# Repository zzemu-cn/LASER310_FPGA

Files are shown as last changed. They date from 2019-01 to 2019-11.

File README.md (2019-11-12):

# LASER310 FPGA

Welcome to LASER310_FPGA project. This project is an attempt to recreate the once famous VZ300/Laser310 computer in 80's on Altera Cyclone based FPGA boards.

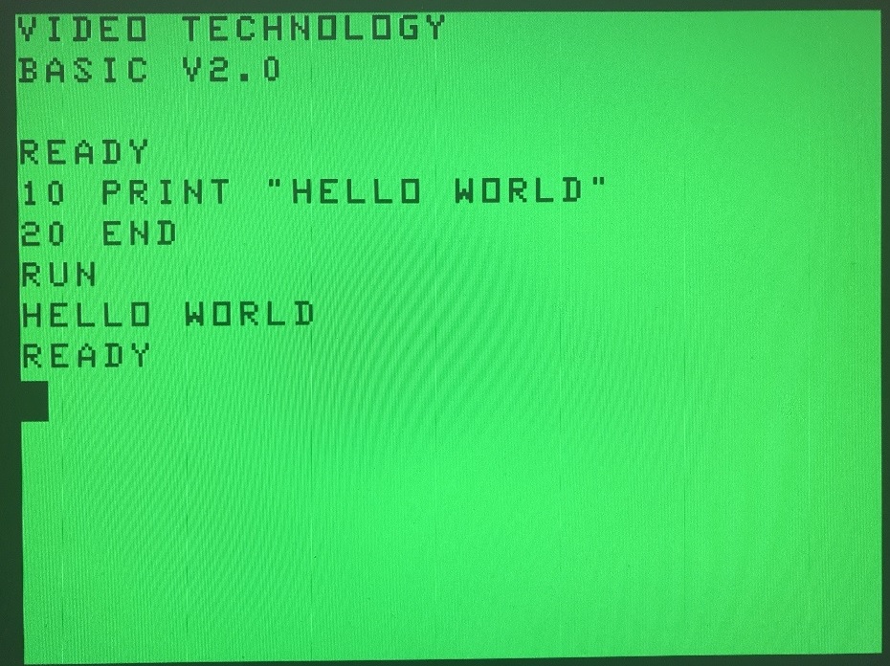
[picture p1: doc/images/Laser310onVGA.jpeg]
Laser310 on VGA


***Software requirment:***   
Quartus 13.0 web edition for projects except DE0_CV. For DE0_CV, you need 18.0 or newer.   

***Features implemented:***
1. MC6847 /w VGA output
2. Super high resolution mode (256*192)
3. Cassette input/output emu
4. Laser310 internal ROM/DOS ROM on flash
5. Enable external ROM with onboard switches at runtime.
6. VZ200 support
7. 256K RAM module
8. Buzzer output
9. PS/2 keyboard support (Ctrl+F12 to reset).
10. 12.5MHz overclock on SW0

***Planned***

1. Z80 bus on GPIO mapping.
2. Floppy emu support

***Screenshots***  
IORQ output n,5 captured on GPIO1  
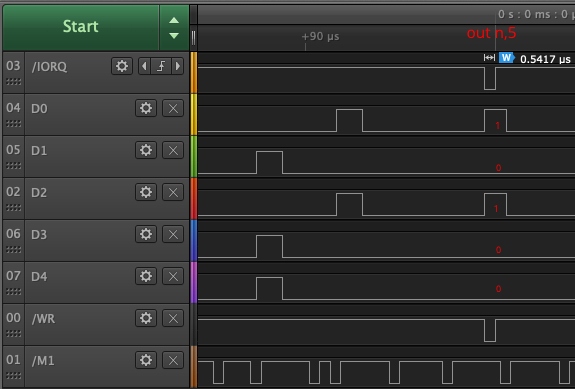
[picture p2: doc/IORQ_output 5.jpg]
IORQ on output
  

***Supported boards***

- Terasic DE0
- Terasic DE0_CV
- Terasic DE1
- Terasic DE2
- Terasic DE2-70
- Terasic DE2-115

***Folder structures***

doc_LASER310:

Laser310 Ext Basic P1.5c and user manual.

Laser310 System B and user manual.

Laser310 Monitor and user manual

Cassette output encoding details.

Laser310 keyboard encoding schema

Laser310 oscilloscope screenshot of cassette output 

rom:

VZ300/Laser310 roms

Software:

development tools for this project. 

vz:

Some come games for testing.

SYSTEM-B.vz is a binary file loading/saving tool for cassette/disk on Laser 310.

BASIC_P1.5C.vz is an extended Basic for Laser 310 developed by XinMin Peng in 80's.

MONITORR.vz is a Laser 310 system monitor.

More details on these VZ300/Laser310 softwares to follow.

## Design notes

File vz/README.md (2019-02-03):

System B : Utility for loading and saving binary files. See [instructions](./SYSTEM-B.md) here.  
Monitor :  Z80 monitor runs on Laser310  
Basic P1.5C : Ext. Basic P 1.5C

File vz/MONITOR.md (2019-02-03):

Laser 310 Z80 Monitor instructions:

Entrying Monitor from Laser 310 Basic environment:
MON

Commands:
  * A - 
  * D - 
  * I - Cassette input
  * O - Cassette output
  * W - Write
  * F - Display HEX values
  * L - 
  * M - Memory block move
  * B - Breakpoint
  * E - Execute
  * R - Register display
  * X - 
  * D - Print

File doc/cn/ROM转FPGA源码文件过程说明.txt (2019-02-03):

环境：Windows 10 64位版本。
软件：php

一、php 安装设置
    转换程序是用 php 编写的，需要安装 php 解释程序。
    通过php官方网站下载。
    http://php.net/
    https://windows.php.net/download/

   下载最新版本
   https://windows.php.net/downloads/releases/php-7.3.1-nts-Win32-VC15-x64.zip
   解压缩到 C:\php 目录，并加入到系统执行路径PATH中。

   运行php需要安装对应的MS的VC运行库。
   https://aka.ms/vs/15/release/VC_redist.x64.exe
   https://aka.ms/vs/15/release/VC_redist.x86.exe

   在windows命令行执行 php -v 看是否能够执行。

二、对字库文件进行调整
    这里有个特例，就是需要对字库文件进行调整。
    LASER310的字符点阵（8 x 12点阵256个字符）行数不是2的倍数，不转换，编写视频模块很困难。

三、把 rom 转换为对应的 mif 文件
    fpga 中的 rom 加载有两种方式：一是把 rom 直接写入 flash 芯片。另一种就是用fpga芯片自带块ram来仿真rom。
    为了便于不同开发板之间的移植，该设计方案采用的是块内存来实现rom。
    编译（综合）项目前，需要把 rom 的二进制文件转换为源文件。

    例如，在项目目录为D:\LASER310_FPGA时，命令如下：
    D:
    cd D:\LASER310_FPGA_prj\LASER310_FPGA\rtl
    php gen_mif.php ..\rom\VZ200_4K.FNT charrom_4k.mif
    php gen_mif.php ..\rom\vtechv20.u12 sysrom.mif
    php gen_mif.php ..\rom\vzdos.rom dosrom.mif
    php gen_mif.php ..\rom\boot_rom.bin boot_rom_6000.mif

    这四条命令分别把字库字模文件、系统rom文件、磁盘rom文件、自动化加载程序 转换为FPGA的rtl源代码。

四、生成模拟磁带模块的预装载数据
    模拟磁带模块可以设置一个默认的装载磁带数据。可以通过命令把 vz 文件转换为FPGA的rtl源代码。
    例如，在项目目录为D:\LASER310_FPGA时，命令如下：
    D:
    cd D:\LASER310_FPGA\rtl
    php vz2mif.php ..\vz\PUCKMAN.AC3A.vz cass_ram.mif
    php vz2mif.php ..\vz\SYSTEM-B.vz cass_ram_4k.mif
    php vz2mif.php ..\vz\MONITORR.vz cass_ram_4k.mif

    根据选定的模拟磁带缓冲区大小，生成对应的文件。
    cass_ram.mif
    cass_ram_4k.mif
    cass_ram_8k.mif
    cass_ram_16k.mif

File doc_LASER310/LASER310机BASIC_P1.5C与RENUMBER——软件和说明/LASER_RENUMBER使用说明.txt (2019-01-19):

摘录自《Laser310微电脑软硬件系统剖析》彭辛岷

LASER RENUMBER
功能：
（1）重编BASIC程序行号，并相应修改下列语句中的目标行号参数：GOTO，IF…THEN…ELSE，GOSUB，RUN，LIST，LLIST，ON…GOTO，ON…GOSUB，ONERR，RESUME，DEL，POP，以及用直接行号作参数的RST语句；
（2）优先使用显示文本区存放数据，处理300个以下的句内行号参数可不占用户程序区；
（3）能将程序中有错误的行号参数首字符变成字母（以A~J代替0~9），提示用户修改；
（4）处理过程中发生内存不够使用时可报告当前处理到的行号，以便删节后再重编；
（5）两个以上程序拼接后（行号不成升序）重编，可保证各自目标行号不致错乱；
（6）产生过大行号（≥60000）时能自动加以调整；
（7）速度快，安全性好。

软件制作方法：将机器码按址送入内存后，将其首、末地址置入用户程序首、末址指针单元，存盘或记带；以后用BLOAD（磁盘）和CLOAD（磁带）装入内存。用CLOAD装入后应执行NEW以修正程序区指针（如先已有BASIC程序，可再用PRINT&PST恢复之）。

调用方法：
（l）本程序须在Pl.5D系统支持下方能处理扩展功能语句；P1.5D是将P1.5C文本中7D2FH~7D39H的内容改为“F5 E5 21 12 75 CD A4 06 C3 4A 1E”，将7B9FH的内容改为44H而成。调用的命令为：RENUN首行行号，行号增量；语法规则不变。
（2）在V2.0支持下，可用USR函数调用，入口地址为74D6H，执行POKE 30862,214:POKE 30863,116后，调用格式为：A=USR(0)'首行行号,行号增量（注意号'不能省略）；参数用法同P1.5。

注意：
（1）本程序因利用显示RAM，运行中荧光屏出现点线干扰及图案字符，均属正常现象；
（2）使用MODE(1)会清除本程序，用USR调用前请证实程序的存在；
（3）重编后程序长度改变，请留心与程序中USR、POKE等有关的地址是否变化；
（4）对REM、PRINT等语句不作处理，

请注意原来有关行号的注释和屏幕提示是否仍然正确，以及使用&ERL（出错行号函数）的语句内容。

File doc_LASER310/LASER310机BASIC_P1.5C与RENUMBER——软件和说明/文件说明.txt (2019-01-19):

目录下的两个程序来自《Laser310微电脑软硬件系统剖析》彭辛岷

根据书中的代码建立了两个文件
LASER_BASIC_P1.5C.txt
LASER_RENUMBER.txt

然后通过命令 php hex_txt2bin.php 生成
BASIC_P1.5C.vz
BASIC_P1.5C.7B04.bin

RENUMBER.vz
RENUMBER.74D3.bin

bin 只含有数据，可以用来反汇编学习。

由于对原书中的程序字符识别可能出现差错，不能保证生成的程序与原始代码一致。

hex_txt2bin.php 是转换脚本源程序。

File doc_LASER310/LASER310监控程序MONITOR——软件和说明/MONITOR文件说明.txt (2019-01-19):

LASER310监控程序MONITOR文件说明

MONITORR 原版的MONITOR程序
MONITOR 解密版的MONITOR监控程序

MONITOR是一个Laser-310监控程序，这个程序类似于Apple II 的Call-151，可以读写内存，汇编，反汇编等。但是因为太大16K内存的310上基本上只能看ROM的内容，加装了16K/64K卡的机器，用这个程序比较实用。

命令：
MON 由BASIC进入MONITOR
E 退出MONITOR返回BASIC

--------------------------------

Monitor发行版是加密的，一加载就自动运行。并且破坏现场。也就是说从monitor里也没法录它自己。
文件MONITOR是由上海董启文解密录制的。
原版MONITOR可以用“B文件系统”直接解密。
MONITOR的使用说明是Bill的笔友张浩写的。

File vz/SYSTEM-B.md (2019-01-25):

Laser310 System B readme  

System B is a utility published on Aug 16 of 1987 issue of "Software" journal. Authors are Luo, Shouzhang and Luo, Ya.
When loading a binary file from cassette on Laser 310, the ROM binary program loader will automatically make a call to the entry point and start running it.
With this utility you can load a binary file from cassette and floppy, make a copy of this file to casette.  

The System B itself is only 190 bytes, designed to be loaded to the high end of display RAM.
Commands:  
R ["filename"] - Load binary file from cassette  
L "filename" - Load binary file from floppy  
W ["filename"] - Write file to cassette as binary file  
V ["filename"] - Verify binary file on cassette  
E - Exit from system  

Notes:  
* System B is compatible with Laser 310 Monitor and DOS Basic 1.2 or any file lives from 7AE9 to B7FF and 7200 to 76FF.
* L command is NOP on diskless system.
* W command will create an identical copy of loadded B file, runs well without System B.
* R/L command, it stores the start address and end address in 77BB and 77BE. They remain unchanged after you exit from System B.
* System B is loadded in high-end of VRAM, MODE(1) command will clean this area.

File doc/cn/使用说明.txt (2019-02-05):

开关0 加速模式 TURBO_SPEED
开关1 加载 DOS ROM
开关2 扩展绘图模式支持 SHRG

开关4...6 地址0000H 16K系统 ROM 切换
开关7...9 地址4000H 8K ROM 切换

键盘功能：上下左右，右Shift，Esc模拟Ctrl-Break, Backspace左
Ctrl+F12 系统复位 reset
button0 系统复位 reset

Ctrl F1 ... F8  Auto Start ROM 自动化加载程序 固化程序 4000 D000 E000 F000
L-Ctrl F1 ... F8 自动化加载 vz 文件，启动代码未完成

左line in录音输入
左line out录音输出

右line out喇叭输出

vz 可以通过 WAV2VZ.exe 转换为 wav 文件。

================================

虚拟磁带
敲入命令 CRUN
（下步改进，自动输入CRUN命令）
F9  播放 RAM 缓冲区的磁带数据
F10 停止播放

可以通过software目录下的emu_cass_key_gui.exe上传vz磁带文件

================================

虚拟键盘
通过串口通信软件，如 putty
设置 57600 8
插入LF

特殊命令
按键      操作
_         播放虚拟磁带
Backspace 左移动
Ctrl+C    Ctrl+Break
Return    Return

可以接受的字符输入
数字 大写 符号 图形字符（对应的小写）

================================
编译项目
目前支持的开发板
友晶的 ALTERA DE0
友晶的 ALTERA DE1
友晶的 ALTERA DE2
友晶的 ALTERA DE2-70
友晶的 ALTERA DE2-115

编译前，需要修改源文件 LASER310_FPGA\rtl\LASER310_TOP.v

//`define	DE0
`define	DE1
//`define	DE2
//`define	DE2_70
//`define	DE2_115

打开对应的选项。

进入目录 LASER310_FPGA\rtl
通过 mif 文件生成ROM。
php gen_mif.php ..\rom\VZ200.FNT charrom.mif
php gen_mif.php ..\rom\VZ200_4K.FNT charrom_4k.mif
php gen_mif.php ..\rom\vtechv20.u12 sysrom.mif
php gen_mif.php ..\rom\vzdos.rom dosrom.mif
php gen_mif.php ..\rom\boot_rom.bin boot_rom_6000.mif

生成默认的模拟磁带数据:
php vz2mif.php ..\vz\BASIC_P1.5C.vz cass_ram_4k.mif
php vz2mif.php ..\vz\BASIC_P1.5C.vz cass_ram.mif
php vz2mif.php ..\vz\MONITORR.vz cass_ram.mif
php vz2mif.php ..\vz\SYSTEM-B..vz cass_ram.mif
php vz2mif.php ..\vz\PUCKMAN.vz cass_ram.mif

也可以通过命令
vz2mif.exe 02.vz 02.mif

================================
烧录ROM文件
随着系统功能扩充，部分开发板的片上内存不足，需要使用FPGA外接 flash 来存储 ROM数据。
目前 DE1 和 DE2 开发板需要烧写 FLASH。

首先要生成写入 FLASH 的二进制数据文件。
执行
 CD flash_build
 php gen_rom.php 可以生成 flash_rom.bin 这个文件。

对于友晶的DEx系列开发板，厂商提供了烧写 FLASH 的工具 DEx_control_panel，可以在最新的随机光盘文件中找到。
对于DE1开发板，可以参考“DE1烧写flash的方法.txt”。
通过FLASH烧写工具，把文件 flash_rom.bin 写入开发板。记得先擦除后烧写。

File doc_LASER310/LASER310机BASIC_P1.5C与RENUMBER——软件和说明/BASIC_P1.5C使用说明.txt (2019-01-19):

摘录自《Laser310微电脑软硬件系统剖析》彭辛岷

P1.5的扩展功能

    本系统在V2.0的基础上，发据出Level II的全部功能，模拟了APPLESOFT和PC-1500 BASIC的部分功能，还具有一些上述系统都不具备的独特功能。扩展的语句命令和函数共计四十三种。现将保留词、用法和功能简介如下。

    系统功能
    （1）BYE
	退出
    退出P1.5，重新启动V2.0。

    BASIC程序管理功能
    （1）AUTO 首行行号，行号增量
	自动产生行号
    按给定参数自动产生行号，接受输入的程序行。回车后按增量产生下行行号……直至行号>65529或按了BREAK为止。如某一参数缺省则自动设为0。程序区已有与所产生的行号相同的程序行时，显示该行，光标在行末。

    （2）RENUN 首行行号，行号增量
    重编行号
    可按规定系列将程序行号全部重编，某一参数缺省时自动设定为10。因系统规模所限，本功能仅为简易型，不处理语句中的目标行号，需用户自行修改。如需全部用程序处理，请采用笔者开发的“LASER RENUMBER”程序。

	（3）DEL 起始行号——结束行号
	成片删除
    删除指定范围的全部程序行；如起始行号缺省，则删除指定行号及它前面的所有行。

	（4）PLOAD “文件名”
	拼接读带
    在保存内存中现有文件的同时，从磁带上装入一个BASIC文件，以便二者拼接。
    （5）MERGE
	程序拼接
    用PLOAD命令装入供拼接的程序后，此命令可将它同内存原有程序拼接为一个程序。后调入程序排列在前，原有程序接在其后；并不按行号大小顺序。如拼接后行号顺序颠倒，仍可按排列顺序执行，但GOTO等语句可能出错，所以一般应重编行号。
    （6）MERGE 0
	撤销拼接
    当错调拼接文件，装载出错或意图改变时，此命令可清除装入的内容，恢复原有程序
	（7）PRINT&PST
	恢复被清除的程序
    可恢复被NEW命令清除的BASIC程序。如NEW后又键入了新的程序行，只要尚未达到原来程序的长度，亦可部分恢复显示（首行可能不正确），但程序首址已变为当前地址。如NEW后使用过Pl.5扩展命令，或在直接命令中使用过变量，也只能恢复未被新的变量区覆盖的部分。以上两种情况都可用LOMEM 0命令使残余程序段复位到程序区起始端。

    机器语言程序管理功能
    （1）LOMEW低端地址
	低端内存保护

——84——

    设定BASIC程序区起始地址，从7B04H（31492）到设定地址的前一单元，不受系统的控制，为用户所有。在已经输入BASIC程序以后，仍可用此命令开辟保留区；已开辟保留区还可重新改变其地址。BASIC程序将自动在内存中移动，不会遭到破坏。地址参数取十进制正值（31492~65535），保留区内用户可用来存贮数据的最低地址为31492，前面是预置的BASIC启动程序。

	（2）LOMEM 0
	撤销保留区
    清除保留区数据，BASIC首址前移至7AE9H，程序不受影响。

	（3）CALL 入口地址
	调用机器语言子程序
    从指定地址开始执行机器程序，遇到返回指令时返回BASIC程序的断点继续运行。地址参数取十进制正值（0~65535）。

	（4）SAVEB “文件名”
	二进制文件写入磁带
    将低端用户保留区7B04H以后的全部内容，以二进制格式存贮在磁带上。记带期间禁按BREAK。

	（5）SAVEA “文件名”
	二进制/BASIC复合文件写入磁带
	将BASIC程序连同保留区内全部信息以BASlC文本文件的格式记入磁带。以后装入内存可自动调整指针，并启动BASIC程序。

	显示功能
    （1）SPEED 延时值
	显示、打印速度控制
    设定显示每一行之间的延时值。取0为正常速度，取1~256时间间隔次第加长，SPEED 256时显示行间约间隔一分钟。延时对显示、打印数据及程序清单均有效。中途按“.”键，恢复正常速度。

	（2）&P0S(0)
	取光标的行位置
    其值为光标在当前的行中的位置（0~31）

	数据处理功能
	（1）DEFDBL 字母或字母范围
	定义双精度变量
    把以指定字母开头的变量都定义为双精度变量，使能保持16位有效数字；带类型标志$、%和！者除外。赋给双精度变量的数值应该是双精度的，否则六位以后的数字无意义。精度常数用#号标注。不同精度的变量或数值间进行运算时结果为较高精度类型。字母可分别指定，用逗号分隔，也可按英文字母表的顺序，指定范围，如DEFDBL N, M, D-G。

	（2）DEFINT 字母或字母范围
	定义整型变量
    将以指定字母开头的变量都定义为整型（带$、！标志者除外），存放整数（32767≥N≥-32768）。用法同上。

    （3）DERSTR 字母或字母范围
	定义字符串变量
    将以指定字母开头的变量均定义为字符串型（带%、！标志者除外）。用法同上。

	（4）DEFSNG 字母或字母范围
	定义单精度变量
    将以指定字母开头的变量均定义为单精度型（带%、$标志者除外）。由于系统初始化时已将所有变量均定义为单精度型，它一般只在重新定义时使用。用法同上。变量重新定义后即失去原有的值。

	（5）&CDBL(表达式)取双精度值

——85——

    函数为自变量的双精度值。

    （6）&CSNG(表达式)
	取单精度值
    函数为自变量的单精度值。如自变量是双精度时，多余位数四舍五入。

    （7）&CINT(表达式)
	取整型值
    函数为自变量的整型值（不大于自变量的最大整数）。自变量的范围是：32767≤N≥-32768。

	（8）&FIX(表达式)
	数值截尾
    取自变量的整数部分。当自变量为负数时，函数值将大于自变量。如：&FIX(-3.14)=-3，而INT(-3.14)=-4。

	（9）&STRING$(长度,字符)
	同一字符的字符串
	函数值为由指定的同一字符组成的、指定长度的字符串。参数可为表达式。长度受字符串区容量的限制；要先用CLEAR开辟足够的空间。字符串自变量多于一个字符时，只取首字符。

	（10）RANDOM
	打开随机数发生器
    由于产生RND函数的种子值是一定的，并由同一子程序计算而得，所以只是伪随机数。
在调用RND之前使用本语句，可用当时CPU刷新寄存器的值改变种子值，增加RND函数的随机性。

    监测功能
    （1）TRON
	打开跟踪功能
    BASIC程序运行时将显示所执行的每一行号。

	（2）TROFF
	关闭跟踪功能

	（3）&LAD(表达式)
	取行地址
    自变量为一行号值。函数值为此行在内存的首址。

	（4）&VARPTR(变量名)
	取变量地址
    函数值为指定变量在变量区的首址。

	（5）&MEM
	取空闲内存字节数
    函数值为当前BASIC程序尚可使用的内存空间剩余字节总数。

	（6）&FRE(字符串变量名)
	取空闲字符串区字节数
	函数值为当前字符串区尚可使用的字节总数。自变量可用任一字等串变量名。

	BASIC程序控制功能
    （1）RST 表达式
	重置读数据指针
    参数为一行号值；将读数据指针指向该行，READ语句将从此行开始从BATA语句中读取数据。

    （2）ON 表达式 GOTO 行号1，行号2……
	控制转移根据表达式的值N，转移到第N个行号的行去继续运行。如N大于行号个数，或N<1，则不转移，顺序执行下一语句。

	（3）ON 表达式 GOSUB 行号1，行号2，……
	控制调用子程序
	根据表达式值N，决定调用第N个行号为入口的BASIC子程序。规则同上。

	（4）POP 行号
	清栈转移

——86——

    在用GOSUB转入子程序后，如不需要返回原来的断点，此语句可在执行RETURN清除堆栈功能后，转向指定行号继续运行。

	错误处理功能
    （1）ONERR GOTO 行号
	进入出错转移状态
    此后程序出错时，不再中断运行和显示错误信息，而是转到本语句指定的行号（一般是一个处理错误的子程序入口）去继续运行。

	（2）ONERR GOTO 0
	终止出错转移状态
    取消上一个ONERR语句的作用。如在已经出错并转移后执行此语句，就停止运行，显示原来的错误信息。

	（3）&ERR 取错误代码
    函数值为当前的错误代码，可用以辨别错误的性质。

	（4）&ERL 取出错行号
    函数值为当时产生错误的行号。直接命令出错时其值为65535。

	（5）RESUM 0
	返回到出错的语句
    由于ONERR语句的作用捕获到错误并转入错误处理子程序后，须用RESUE语句结束返回，否则仍处于捕获错误的状态，系统将拒绝处理下一次的错误。本语句是返回出错语句重新执行，之前应采取措施使得错误不再发生，否则陷入无限循环。

	（6）RESTME NEXT
	返回出错语句的下一个语句
	可用来跳过产生错误的语句。

	（7）RESEME 行号
	返回并转移
    从出错状态中返国并转移到指定行号继续运行。

	（8）ERROR 错误编号
	模拟错误
    执行此语句的作用，等效于发生该编号的“错误”。可用于调式错误处理子程序。错误编号=错误代码/2+1。错误编号范围为0~23，如参数值超出，本身就是一种错误（错误编号出界，&ERR=38）。

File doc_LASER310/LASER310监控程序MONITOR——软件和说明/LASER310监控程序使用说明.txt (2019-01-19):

LASER 310监控程序使用说明
张浩

命令：MON 由BASIC进入MONITOR

1、汇编命令A
功能：汇编Z-80指令，并将机器指令码存入内存。
格式：As 键入该命今后，屏幕将显示地址s和汇编提示“ASM...”，等待用户输入Z80指令机器码。用户完成输入后，按下回车，助记符便被会变成指令机器码，并存入从地址s开始的内存单元。

2，反汇编列表命令D
格式：Ds,e
从地址s开始，到地址e结束，列表显示Z80助记符。如e省略，Ds 从地址s开始，列表显示10行助记符。

3、磁带输入命令I
格式：I
从磁带当前位置开始，将遇到的第一个磁带文件装入内存，并显示起止地址。
格式：I:f
把“f”为文件名的文件装入内存。

4、磁带输出命令O
格式：Os,e,f
将起始地址为s，结束地址为e的二进制文件，以f为文件名存入磁带。

5、写入命令W（十六进制）
格式：Ws 键入该命令后，屏幕将显示地址s和s中的内容。当用户键入数据，并按下回车后，新的数据被写入s单元中。如果用户名键入引号后，直接键入字符，该字符的ASCII便写入s中。按下“.”，退出写命令。

6、显示命令F（十六进制）
格式： Fs,e
显示从地址s到e间的数据。如e省略，Fs显示从s开始的8x10个字节数据。

7、显示ASCII码命令L
功能：显示内存中的ASCII码和ASCII码所代表的字符。
格式：Ls,e
同Fs,e

8、数据块移动M
格式：Ms,e,d
将地址s到e中一段数据，移动到以d开始的内存空间，源地址内容不变。

9、设置断点B
格式：Bs
在程序地址s中设置断点，当程序运行到断点时，自动显示所有寄存器的当前内容，并返回MONITOR。

10、消除B命令所设置的断点
格式：C

11、程序运行命令E
格式：Es
从地址s开始运行Z-80程序
格式：E
退出MONITOR，返回BASIC

12、寄存器操作命令R
格式：R
显示所有寄存器在程序中断后的内容
格式：Rr,d
将寄存器r中的内容改为d

13、十进制与十六进制互换X
功能：十进制范围为 0——32767，-32768——-1，十六进制0H——FFFFH
格式：XDd
将十进制数d转为十六进制数
格式：XHh
将十六进制数h转为十进制数

14、打印命令D
格式：Dm
用打印的形式完成监控命令，m为D、F、L等。

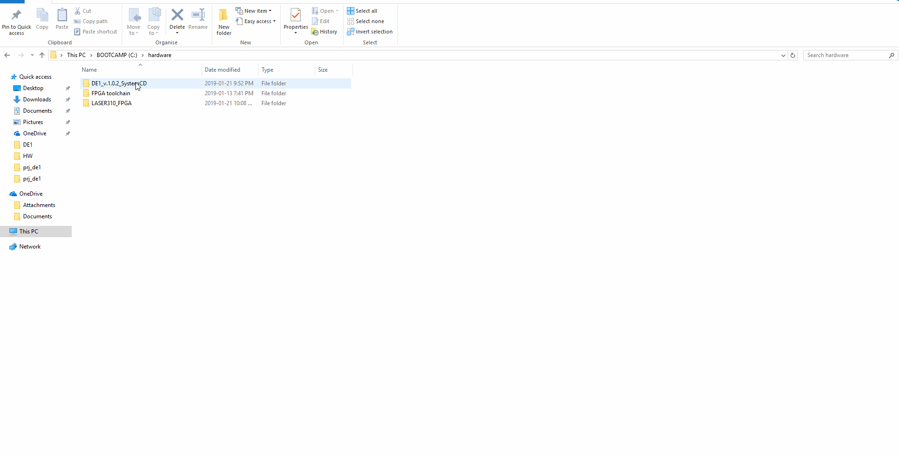
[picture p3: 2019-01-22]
doc/screen_recordings/program flash with ROM bin file.gif

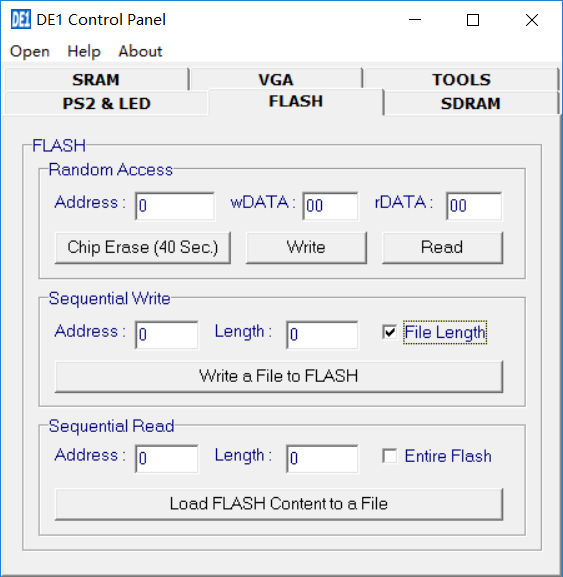
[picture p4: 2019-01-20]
doc/cn/pic4.png

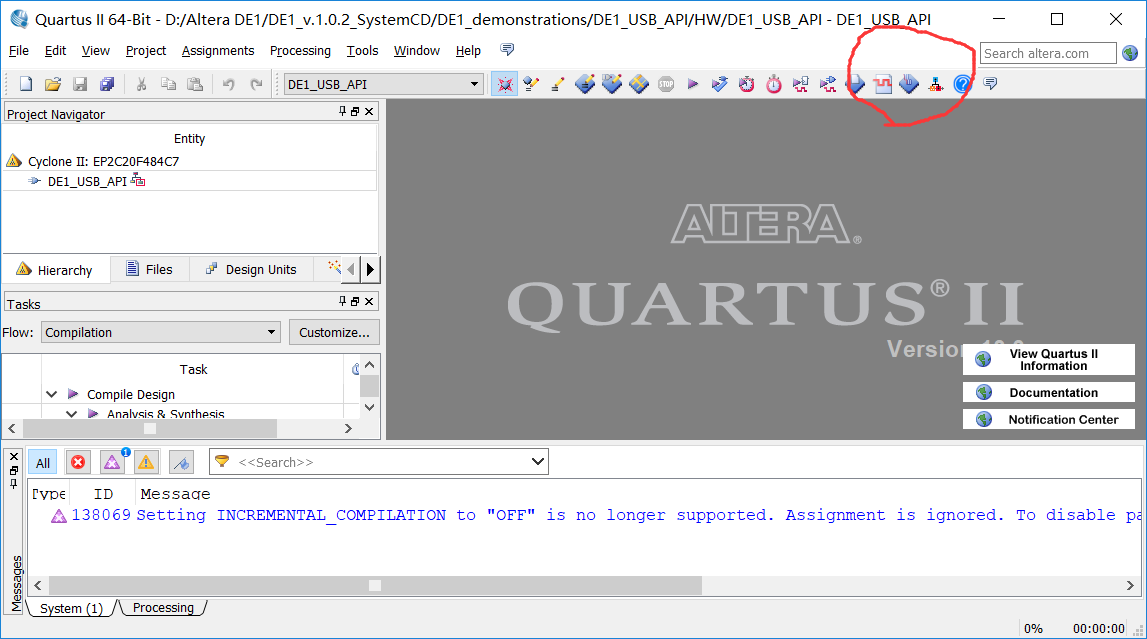
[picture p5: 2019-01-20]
doc/cn/pic1.png

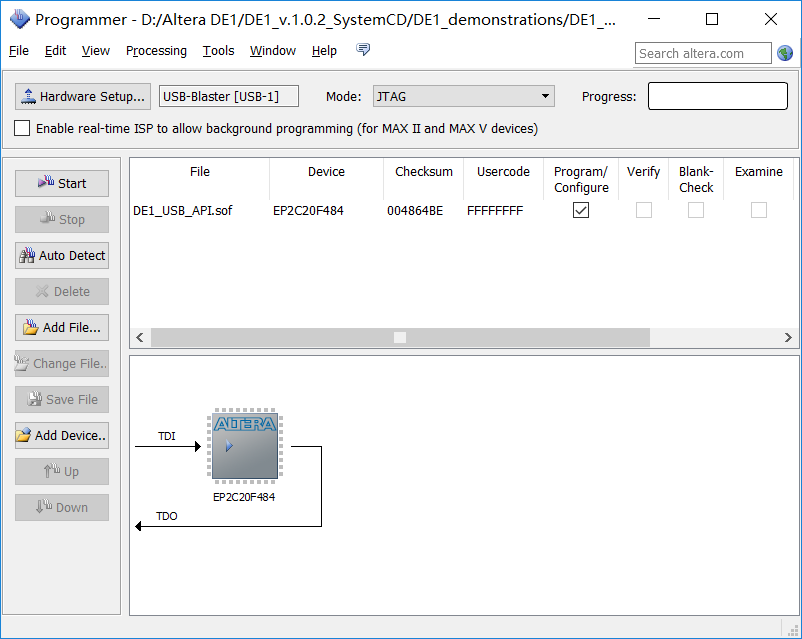
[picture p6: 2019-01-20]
doc/cn/pic2.png

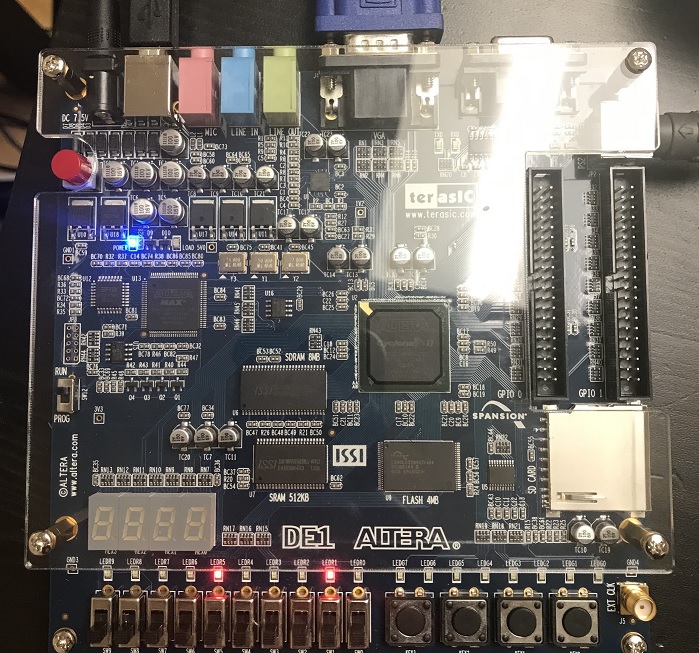
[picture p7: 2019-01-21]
doc/images/DE1.jpeg

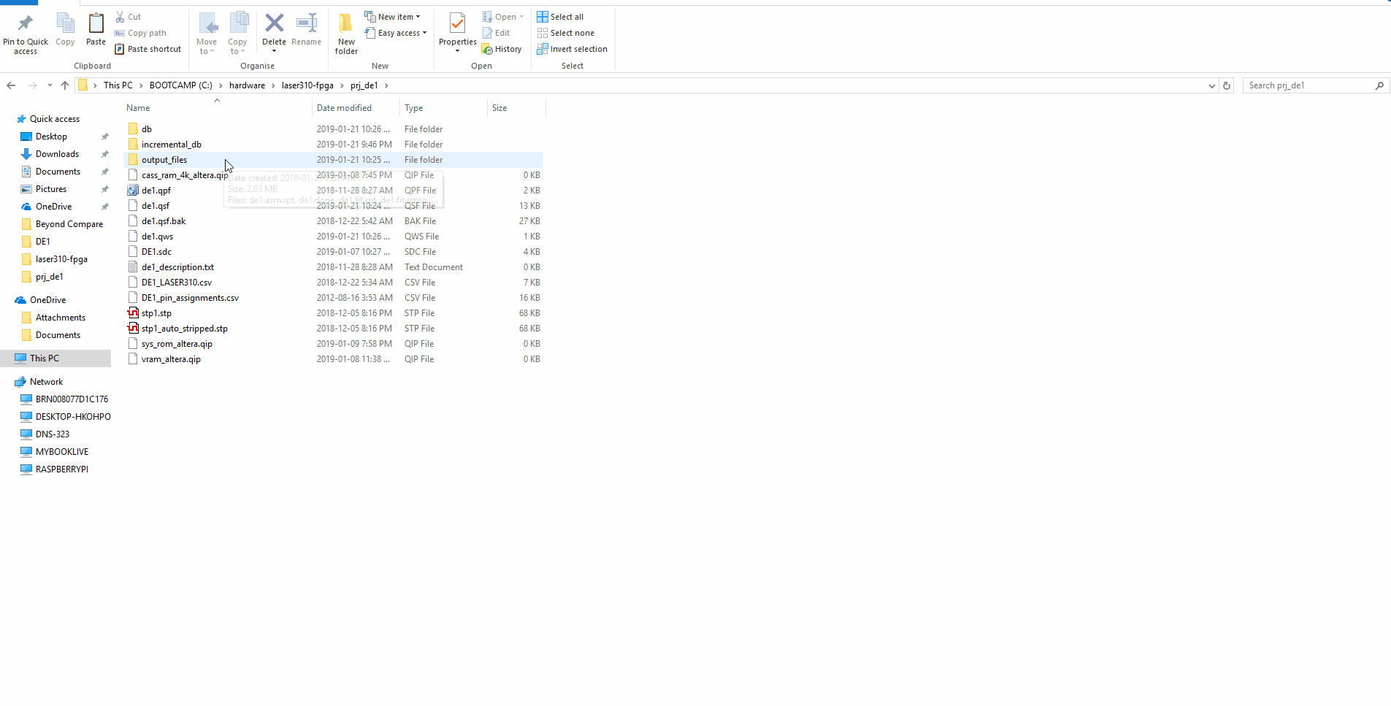
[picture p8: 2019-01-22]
doc/screen_recordings/laser310_fpga_w_built_in_rom.gif

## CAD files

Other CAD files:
prj_de0cv/stp1_auto_stripped.stp
prj_de1/output_files/stp1.stp
prj_de1/stp1.stp
prj_de2_70/output_files/stp1_auto_stripped.stp
prj_de0cv/stp1.stp
prj_de1/output_files/stp1_auto_stripped.stp
prj_de1/stp1_auto_stripped.stp
prj_de2_70/output_files/stp1.stp

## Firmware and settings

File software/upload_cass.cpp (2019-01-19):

// g++ -std=c++17 -o upload_cass upload_cass.cpp vz2cass.cpp UART.cpp -mconsole -DMINGW_HAS_SECURE_API -D_FILE_OFFSET_BITS=64 -IC:/MinGW/include
#include <cstdint>

#include <cstdio>
#include <cstdlib>
#include <cstring>

#define DBG
#include "upload_tool.cpp"

int main (int argc, char *argv []) {

    //char *port = malloc (sizeof (char) * 12); // Just for "straight to test purposes", in production, use the port detection functions instead
    //strcpy(port, "\\\\.\\COM3");

//------------------------------------ Stand-alone function to do their straight work the most synchronous way ------------------------------------

//    AVAILABLE_PORTS *ports;                         // Initializing the struct values
//    ports = malloc(sizeof(AVAILABLE_PORTS));
//    updateAvailablePortsInfo(ports);                // Setup/load time, the function will update the living struct

	int	uart_com_no = 0;

	uint8_t		vz_buf[1024*64];
	uint8_t		buf[1024*64];
	uint32_t	mif_len;
	size_t		vz_len;

    if(argc<2) {
		fprintf(stderr, "usage: upload_cass COMx name.vz\n");
		return 1;
	}

	uart_com_no = getCOMx(argv[1]);
	if(uart_com_no==0) { printf("COMx err %d", uart_com_no); return 1; }

	int err = vz_upload (argv[2], uart_com_no);

	if(!err)
		printf("uploaded completed");

    return err?1:0;
}

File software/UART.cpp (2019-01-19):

/****************************
 *	Module:	UART			*
 *	Author:	Josh Chen		*
 *	Date:	2014/05/15		*
 ****************************/


#include <stdio.h>
#include <windows.h>
#include "UART.h"


//********** Global Variable **********//

#define RX_TIMEOUT      10
#define TX_TIMEOUT      500
#define BUF_SIZE        512
#define MAX_COM_NUM     256

char            UARTErrBuf[BUF_SIZE] = {0};
int             CurrComPort = 0;
HANDLE          UARTHandle[MAX_COM_NUM] = {NULL};
unsigned char   UARTRxBuf[BUF_SIZE] = {0};
unsigned int    UARTRxBufCnt = 0;


//********** Private Function **********//

static void __UartSetLastErr(const char *err, ...)
{
    char szBuf[BUF_SIZE];
    va_list vl;

    memset(UARTErrBuf, 0, sizeof(UARTErrBuf));
    if (NULL != err)
    {
        memset(szBuf, 0, sizeof(szBuf));
        va_start(vl, err);
        vsprintf(szBuf, err, vl);
        va_end(vl);
        sprintf(UARTErrBuf, "*** UART - %s ***\r\n", szBuf);
    }
}

static void __UartSleep(unsigned long ms)
{
    DWORD   beginTick;
    MSG     msg;

    beginTick = ::GetTickCount();
    do
    {
        if (::PeekMessage(&msg, NULL, 0, 0, PM_REMOVE))
        {
            ::TranslateMessage(&msg);
            ::DispatchMessage(&msg);
        }
        ::Sleep(1);
    } while ((::GetTickCount() - beginTick) < ms);
}


//********** Public Function **********//

bool UART_Open(int comPort, int baudRate, int parity, int stopbit)
{
    char            szBuf[BUF_SIZE];
    DCB             dcb;
    COMMTIMEOUTS    comTimeOut;

    if ((comPort > MAX_COM_NUM) || (comPort <= 0))
    {
        __UartSetLastErr("COM%d out of range!", comPort);
        return false;
    }

    if (UARTHandle[comPort-1] != INVALID_HANDLE_VALUE && UARTHandle[comPort-1] != NULL)
    {
        __UartSetLastErr("COM%d has already opened!", comPort);
        return false;
    }

    sprintf(szBuf, "\\\\.\\COM%d", comPort);
    UARTHandle[comPort-1] = ::CreateFileA(
        szBuf,
        GENERIC_READ|GENERIC_WRITE,
        0,
        0,
        OPEN_EXISTING,
        FILE_ATTRIBUTE_NORMAL,
        0
        );

    if (UARTHandle[comPort-1] == INVALID_HANDLE_VALUE)
    {
        __UartSetLastErr("Open COM%d fail.", comPort);
        return false;
    }

    memset(&dcb, 0, sizeof(dcb));
    dcb.DCBlength = sizeof(dcb);
    dcb.BaudRate  = baudRate;
    dcb.ByteSize  = 8;
    //dcb.Parity	= NOPARITY;
    //dcb.StopBits	= ONESTOPBIT;
    dcb.Parity    = parity;
    dcb.StopBits  = stopbit;
    dcb.fOutX     = 0;
    dcb.fInX      = 0;
    dcb.fDtrControl     = DTR_CONTROL_DISABLE;
    dcb.fRtsControl     = RTS_CONTROL_DISABLE;
    dcb.fOutxCtsFlow    = 0;
    dcb.fOutxDsrFlow    = 0;
    dcb.fDsrSensitivity = 0;

    if (!::SetCommState(UARTHandle[comPort-1], &dcb))
    {
        __UartSetLastErr("SetCommState() fail.");
        ::CloseHandle(UARTHandle[comPort-1]);
    		UARTHandle[comPort-1] = INVALID_HANDLE_VALUE;
        return false;
    }

    if (!::SetupComm(UARTHandle[comPort-1], BUF_SIZE, BUF_SIZE))
    {
        __UartSetLastErr("SetupComm() fail.");
        ::CloseHandle(UARTHandle[comPort-1]);
    		UARTHandle[comPort-1] = INVALID_HANDLE_VALUE;
        return false;
    }

    /*comTimeOut.ReadIntervalTimeout         = MAXDWORD;
    comTimeOut.ReadTotalTimeoutMultiplier  = 0;
    comTimeOut.ReadTotalTimeoutConstant    = 0;
    comTimeOut.WriteTotalTimeoutMultiplier = 0;
    comTimeOut.WriteTotalTimeoutConstant   = TX_TIMEOUT;*/
    comTimeOut.ReadIntervalTimeout         = 1;
    comTimeOut.ReadTotalTimeoutMultiplier  = 1;
    comTimeOut.ReadTotalTimeoutConstant    = 1;
    comTimeOut.WriteTotalTimeoutMultiplier = 1;
    comTimeOut.WriteTotalTimeoutConstant   = 1;

    if (!::SetCommTimeouts(UARTHandle[comPort-1], &comTimeOut))
    {
        __UartSetLastErr("SetCommTimeouts() fail.");
        ::CloseHandle(UARTHandle[comPort-1]);
    		UARTHandle[comPort-1] = INVALID_HANDLE_VALUE;
        return false;
    }

    ::PurgeComm(UARTHandle[comPort-1], PURGE_TXABORT|PURGE_RXABORT|PURGE_TXCLEAR|PURGE_RXCLEAR);

    __UartSleep(100);

    CurrComPort = comPort;

    return true;
}


bool UART_Close(int comPort)
{
    unsigned int i = 0;

  	if (comPort == CURRENT_PORT)
        comPort = CurrComPort;

    if (comPort > MAX_COM_NUM || comPort <= 0)
    {
        __UartSetLastErr("COM%d out of range!", comPort);
        return false;
    }

    if (UARTHandle[comPort-1] == INVALID_HANDLE_VALUE || UARTHandle[comPort-1] == NULL)
    {
        __UartSetLastErr("COM%d not opened.", comPort);
        return false;
    }

    CurrComPort = 0;
    for (i = 1; i <= MAX_COM_NUM; i++)
    {
        if (i != comPort && UARTHandle[i-1] != INVALID_HANDLE_VALUE)
        {
            CurrComPort = i;
            break;
        }
    }

    ::PurgeComm(UARTHandle[comPort-1], PURGE_TXABORT|PURGE_RXABORT|PURGE_TXCLEAR|PURGE_RXCLEAR);
    ::CloseHandle(UARTHandle[comPort-1]);
    UARTHandle[comPort-1] = INVALID_HANDLE_VALUE;

    return true;
}


bool UART_ChangePort(int comPort)
{
  	if ((comPort > MAX_COM_NUM) || (comPort <= 0))
    {
        __UartSetLastErr("COM%d out of range!", comPort);
        return false;
    }

  	if (UARTHandle[comPort-1] == INVALID_HANDLE_VALUE || UARTHandle[comPort-1] == NULL)
    {
        __UartSetLastErr("COM%d not opened.", comPort);
        return false;
    }

  	CurrComPort = comPort;

  	return true;
}


bool UART_ClearBuf(void)
{
    if (CurrComPort <= 0)
    {
        __UartSetLastErr("COM port not opened.", CurrComPort);
        return false;
    }

    if (!::PurgeComm(UARTHandle[CurrComPort-1], PURGE_TXABORT|PURGE_RXABORT|PURGE_TXCLEAR|PURGE_RXCLEAR))
    {
        __UartSetLastErr("PurgeComm COM%d error code (%d).", CurrComPort, ::GetLastError());
        return false;
    }

    return true;
}


bool UART_GetStr(char *str)
{
    bool            result = false;
    char            readBuf[BUF_SIZE] = {0};
    unsigned long   readCnt = 0;
  	unsigned long   i = 0;

    if (CurrComPort <= 0)
    {
        __UartSetLastErr("COM port not opened.");
        return false;
    }

    //::ReadFile(UARTHandle[CurrComPort-1], (LPVOID) readBuf, BUF_SIZE, &readCnt, NULL);
  	::ReadFile(UARTHandle[CurrComPort-1], (LPVOID) readBuf, 1, &readCnt, NULL);

    for (i = 0; i < readCnt; i++)
    {
        if (readBuf[i] == '\r' || readBuf[i] == '\n' || UARTRxBufCnt >= BUF_SIZE-1)
        {
            if (UARTRxBufCnt)
            {
                strcpy(str, (const char*) UARTRxBuf);
                memset(UARTRxBuf, 0, sizeof(UARTRxBuf));
                UARTRxBufCnt = 0;
                result = true;
                break;
            }
        }
        else if (readBuf[i] == '\b')
        {
            if (UARTRxBufCnt)
            {
                UARTRxBufCnt--;
                UARTRxBuf[UARTRxBufCnt] = 0;
            }
        }
        else if (readBuf[i])
        {
            UARTRxBuf[UARTRxBufCnt] = readBuf[i];
            UARTRxBufCnt++;
        }
    }

    return result;
}
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

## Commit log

2019-01-19 建立基本结构
    [DE0_LASER310.csv, DE1_LASER310.csv, DE1_pin_assignments.csv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]
2019-01-21 Added Laser310onVGA and DE1
2019-01-22 Added screen recordings
    1. Upload Laser310 fpga with built in ROM
    2. Program flash with ROM bin file
2019-01-31 new version (SHRG FLASH 256K)
    [DE0_LASER310.csv, DE1_LASER310.csv, DE2_115_LASER310.csv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]
2019-02-03 Update LASER310_TOP.v
    Fixed DE1 compiling error.
2019-02-03 Revert "Update LASER310_TOP.v"
    This reverts commit 7a6f2705ce42d9a92efc724cd4e41b9c175a83a9.
2019-02-09 Revert "Update LASER310_TOP.v"
    This reverts commit a2820e00241b3165b1686e27a91118b73b18000e.
2019-02-19 Update LASER310_TOP.v
    for NEXTZ80
2019-02-19 for debug
    [DE1_LASER310.csv, DE1_pin_assignments.csv]
2019-03-05 Port ro Terasic DE0_CV board
    Simple port of the LASER310_FPGA project to the Terasic DE0_CV board.
    Also added some English comments to a few files.
    [DE0CV_LASER310.csv, DE0_LASER310.csv, c5_pin_model_dump.txt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]
